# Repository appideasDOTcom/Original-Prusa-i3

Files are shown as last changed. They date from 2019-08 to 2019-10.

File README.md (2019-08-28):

# Forked from the fine folks at Prusa

Thanks to the fact that Prusa has Open Sourced their designs, I own a cheap i3 MK2 clone that has a few differences from a genuine Prusa, so their models need a few changes to work for me and others like me. My changes should stick mostly to the MK2 branch, and since Prusa doesn't appear merge that branch back to master, I won't either.

# Original Prusa i3 MK2

Original Prusa i3 MK2 is a 3D printer project maintained by PRUSA RESEARCH.
Originates in RepRap project.

This repository contains SCAD files and STLs of the printed parts.

**Links**

 * Prusa Research website : http://prusa3d.com
 * Product page : http://shop.prusa3d.com/en/3d-printers/59-original-prusa-i3-mk2-kit.html
 * Build manual : http://manual.prusa3d.com/c/Original_Prusa_i3_MK2_kit_assembly
 * Firmware : https://github.com/prusa3d/Prusa-Firmware

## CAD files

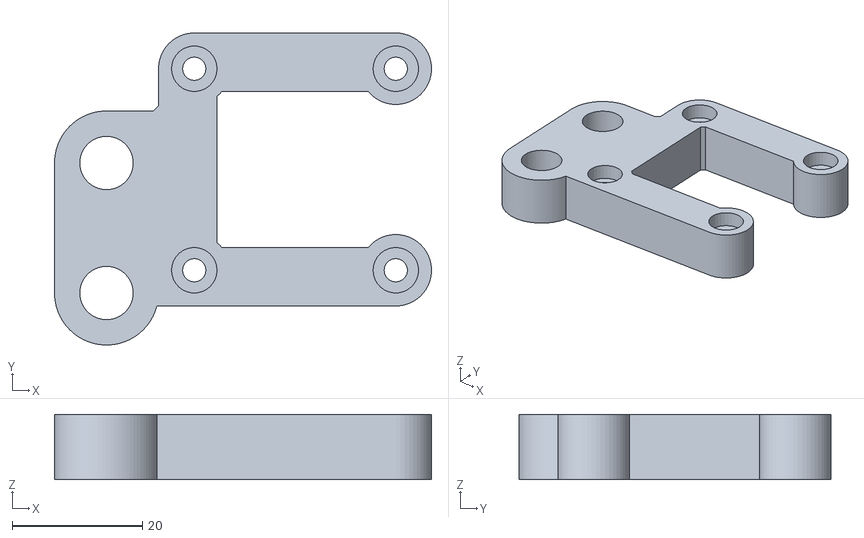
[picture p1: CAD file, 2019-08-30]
Printed-Parts/stl/y-motor.stl
58.0 x 48.0 x 10.0

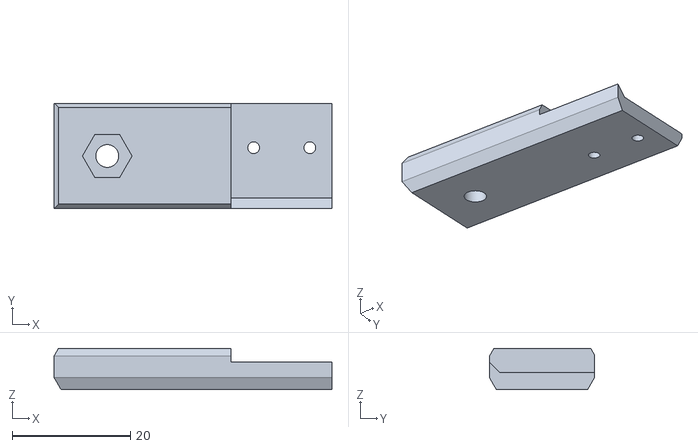
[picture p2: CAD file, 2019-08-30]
Printed-Parts/stl/x-end-adjustable-endstop-bracket.stl
47.0 x 17.8 x 7.00

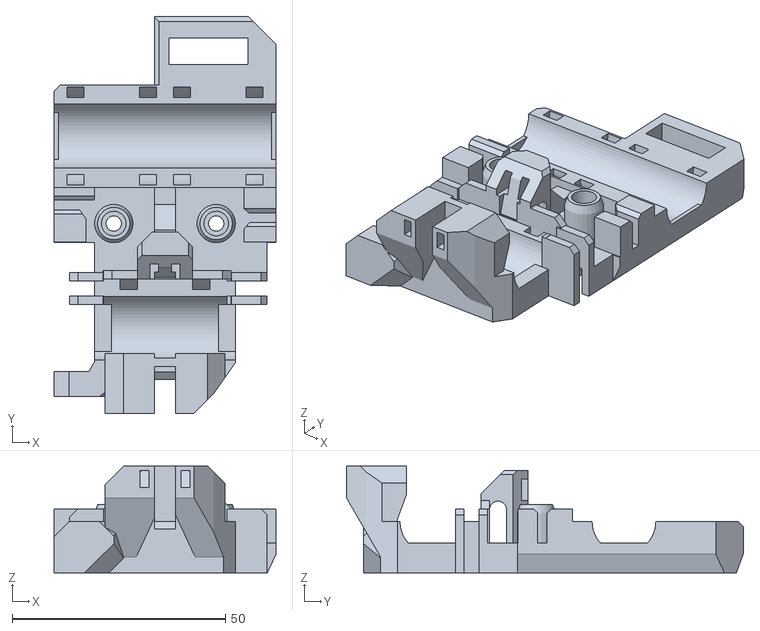
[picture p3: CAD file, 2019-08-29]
Printed-Parts/stl/x-carriage - nub right.stl
52.0 x 93.0 x 25.0

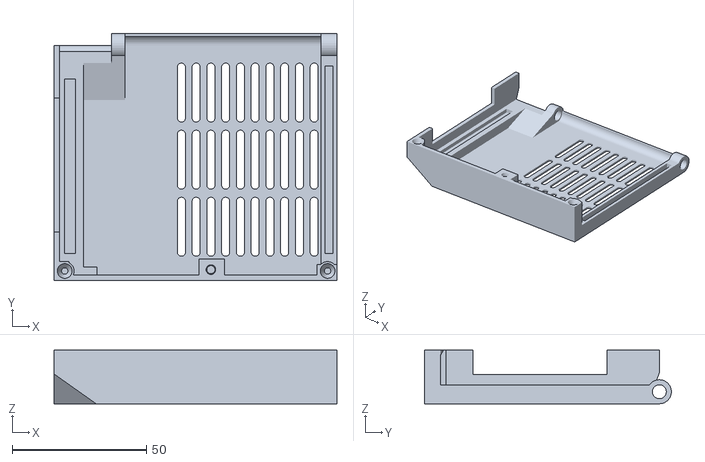
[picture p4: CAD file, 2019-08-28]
Printed-Parts/stl/RAMBo-cover-door.stl
105.5 x 92.0 x 20.0

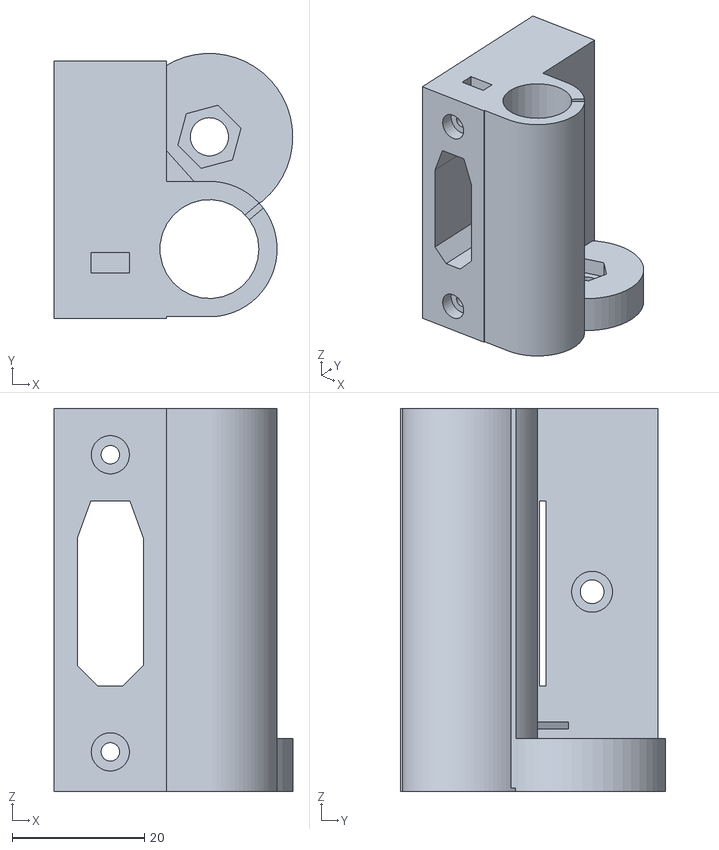
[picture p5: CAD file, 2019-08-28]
Printed-Parts/stl/x-end-idler.stl
36.1 x 40.1 x 58.0

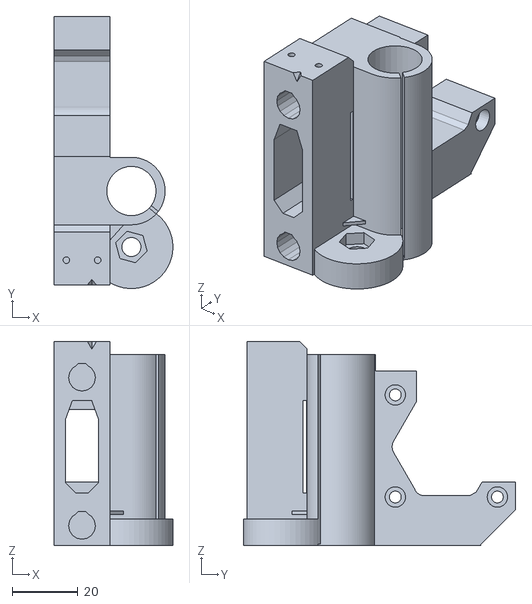
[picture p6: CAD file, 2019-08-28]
Printed-Parts/stl/x-end-motor.stl
36.1 x 82.6 x 62.0

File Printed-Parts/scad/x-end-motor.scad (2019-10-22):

// PRUSA iteration3
// X end motor
// GNU GPL v3
// Josef Průša <iam@josefprusa.cz> and contributors
// http://www.reprap.org/wiki/Prusa_Mendel
// http://prusamendel.org

use <x-end.scad>

extraBaseDepth = 8;

module x_end_motor_base(){
 x_end_base();
 translate(v=[-15,31,26.5]) cube(size = [17,44,53], center = true);
}

module x_end_motor_endstop_base(){
    translate([-23.5,-28.5,58]){
        difference(){
            // Base block
            cube([17,18.2,4]);
            // Nice edge
            translate([-1,10,10])rotate([-45,0,0])cube([20,20,20]);
            } 
        }
}

module x_end_motor_endstop_holes(){
    translate([-23.5,-28.5,58]){
        translate([17/2,7.5,-3]){
            // Back screw hole for endstop
            translate([-4.75,0,0])cylinder(r=1,h=19,$fn=20);
            // Front screw hole for endstop
            translate([4.75,0,0])cylinder(r=1,h=19,$fn=20);
            }
        }
}

module x_end_motor_holes(){
 x_end_holes();
 // Position to place
 translate(v=[-1,32,30.25]){
  // Belt hole
  translate(v=[-14,1,0]) cube(size = [10,46,22], center = true);
  // Motor mounting holes
  translate(v=[20,-15.5,-15.5]) rotate(a=[0,-90,0]) rotate(a=[0,0,90]) cylinder(h = 70, r=1.8, $fn=30);
  translate(v=[1,-15.5,-15.5]) rotate(a=[0,-90,0]) rotate(a=[0,0,90]) cylinder(h = 10 + extraBaseDepth, r=3.1, $fn=30);
  translate(v=[20,-15.5,15.5]) rotate(a=[0,-90,0]) rotate(a=[0,0,90]) cylinder(h = 70, r=1.8, $fn=30);
  translate(v=[1,-15.5,15.5]) rotate(a=[0,-90,0]) rotate(a=[0,0,90]) cylinder(h = 10 + extraBaseDepth, r=3.1, $fn=30);
   translate(v=[20,15.5,-15.5]) rotate(a=[0,-90,0]) rotate(a=[0,0,90]) cylinder(h = 70, r=1.8, $fn=30);
  translate(v=[1,15.5,-15.5]) rotate(a=[0,-90,0]) rotate(a=[0,0,90]) cylinder(h = 10 + extraBaseDepth, r=3.1, $fn=30);
  translate(v=[20,15.5,15.5]) rotate(a=[0,-90,0]) rotate(a=[0,0,90]) cylinder(h = 70, r=1.8, $fn=30);
  translate(v=[1,15.5,15.5]) rotate(a=[0,-90,0]) rotate(a=[0,0,90]) cylinder(h = 10 + extraBaseDepth, r=3.1, $fn=30); // This is the hole to nowhere

  // Material saving cutout 
  translate(v=[-10,12,10]) cube(size = [60,42,42], center = true);

  // Material saving cutout
  translate(v=[-10,40,-30]) rotate(a=[45,0,0])  cube(size = [60,42,42], center = true);
  // Motor shaft cutout
  //#translate(v=[0,0,0]) rotate(a=[0,-90,0]) rotate(a=[0,0,90]) cylinder(h = 70, r=17, $fn=6);
 }
}

// Motor shaft cutout
module x_end_motor_shaft_cutout(){
    union(){
    difference(){
        translate(v=[0,32,30]) rotate(a=[0,-90,0]) rotate(a=[0,0,90]) cylinder(h = 70, r=17, $fn=6);
       
        translate(v=[-10,-17+32,30]) cube(size = [60,2,10], center = true);
        translate(v=[-10,-8+32,-15.5+30]) rotate(a=[60,0,0]) cube(size = [60,2,10], center = true); ///
        translate(v=[-10,8+32,-15.5+30]) rotate(a=[-60,0,0]) cube(size = [60,2,10], center = true);
        
        
    }
    translate(v=[-40,25.2,-11.8 +30]) rotate(a=[0,90,0]) cylinder(h = 40, r=3, $fn=30);
    translate(v=[-40,19.05,30]) rotate(a=[0,90,0]) cylinder(h = 40, r=3.5, $fn=100);
}
}




// Final part
module x_end_motor(){
 difference(){
     union(){
            x_end_motor_base();
            x_end_motor_endstop_base();
            extraBase();
         }
  x_end_motor_shaft_cutout();
  x_end_motor_holes();
  x_end_motor_endstop_holes();    
      
      translate([-12,-42,65]) rotate([-35,0,0])  rotate([0,0,45]) cube([10,10,10]);
      translate([-15,8.5,6]) rotate([90,0,0]) cylinder(h=5, r=5, $fn=30);   
      translate([-15,8.5,51]) rotate([90,0,0]) cylinder(h=5, r=5, $fn=30);   
      translate([-15,3.5,6]) rotate([90,0,0]) cylinder(h=3, r1=5, r2=4, $fn=30);   
      translate([-15,3.5,51]) rotate([90,0,0]) cylinder(h=3, r1=5, r2=4, $fn=30); 
      //#translate([-16,-40,0])cube([50,100,100]);   
 }
 
}

module extraBase()
{
    translate( [-31.5, 10.5, 0] )
    {
        cube( [extraBaseDepth, 42.5, 53] );
    }

}

// x_end_motor();

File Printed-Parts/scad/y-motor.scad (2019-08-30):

// PRUSA iteration3
// Y motor mount
// GNU GPL v3
// Josef Průša <iam@josefprusa.cz> and contributors
// http://www.reprap.org/wiki/Prusa_Mendel
// http://prusamendel.org

//include <configuration.scad>

renderEndstopMount = false;

module motorMountArm()
{
   translate(v = [-21+4.5,0,5]) cube(size = [9,31,10], center=true);
   translate(v = [-15.5,-15.5,0]) cylinder(h = 10, r=5.5, $fn=50);
   translate(v = [-15.5,+15.5,0]) cylinder(h = 10, r=5.5, $fn=50);
}

// Pull Prusa's motor mount into a module so it's easier to work with in isolation
module motorMount()
{
// Motor holding part
   translate(v = [29,-21+50,0])
   {
      translate(v = [-21+4.5,0,5]) cube(size = [9,31,10], center=true);
      translate(v = [-15.5,-15.5,0]) cylinder(h = 10, r=5.5, $fn=50);
      translate(v = [-15.5,+15.5,0]) cylinder(h = 10, r=5.5, $fn=50);
      translate([-21,7,0]) rotate([0,0,45]) cube([2, 2, 10]);

      difference()
      {
         {
            union()
            {
               rotate( [0, 0, 90] ) 
               {
                  motorMountArm();
               }
               rotate( [0, 0, -90] ) 
               {
                  motorMountArm();
               }
            }
         }
         {
            translate( [31, 0, 0] )
            {
               boltHoles();
            }
         }
      }

      //end stop
      // My printer's end-stop is on the opposite end of the motor mount
      if( renderEndstopMount )
      {
         translate(v = [-10.5,+15.5,0]) cylinder(h = 10, r=5.5, $fn=50);
         translate([-12,0,0]) cube([7, 15, 10]);
         translate([-16,16,0]) cube([6, 5, 10]);
         translate([-21+6,8,0]) cube([12-2, 5, 28]);
         translate([-21+6-2,8-5,0]) cube([4, 10, 28]);
         translate([-21+9.5-2,7,0]) rotate([0,0,45]) cube([2, 2, 28]);    
      }

   // Joins motor holder and rod plate
   translate(v = [-29,-21,0]) cube(size = [14,30,10]);
 }
}

module y_motor_base(){
 
motorMount();

 // Front holding part
 translate(v = [0,10,0]) cylinder(h = 10, r=8, $fn=80);
 translate(v = [0,20,5])cube(size = [16,20,10], center=true);	
 translate(v = [0,30,0])cylinder(h = 10, r=8, $fn=80);
}

module boltHoles()
{
   // Screw head holes
  translate(v = [-15.5,-15.5,-1]) cylinder(h = 10, r=1.8, $fn=20);
  translate(v = [-15.5,+15.5,-1]) cylinder(h = 10, r=1.8, $fn=20);
  // Screw holes
  translate(v = [-15.5,-15.5,7]) cylinder(h = 7, r=3.5, $fn=30);
  translate(v = [-15.5,+15.5,7]) cylinder(h = 25, r=3.5, $fn=30);
}

module y_motor_holes(){
 translate(v = [29,-21+50,0]){
  boltHoles();
 }
 translate(v = [0,10,-1]) cylinder(h = 12, r=4.1, $fn=50);	
 translate(v = [0,30,-1]) cylinder(h = 12, r=4.1, $fn=50);
 
 //endstop
    translate([25,29,0])  cylinder(h = 29, r=8, $fn=20); 
   
    translate([18,45,15]) rotate([90,0,0]) cylinder(h = 10, r=0.8, $fn=20);
    translate([18,42.2,15]) rotate([90,0,0]) cylinder(h = 2, r1=1.2, r2=0.8, $fn=20);
 
    translate([18,45,24.5]) rotate([90,0,0]) cylinder(h = 10, r=0.8, $fn=20);
    translate([18,42.2,24.5]) rotate([90,0,0]) cylinder(h = 2, r1=1.2, r2=0.8, $fn=20);
   
    // endstop corner cutout
    translate([-5-2,30,28]) rotate([0,45,0]) cube([15, 19, 15]);	
    translate([-1,41,10])  cube([15, 5, 19]);	
    translate([27,33,0]) rotate([0,0,45]) cube([5, 5, 28]);	
    translate([12-2,28,10.01]) rotate([0,0,45]) cube([5, 5, 28]);
    
    // This cuts through the extended Y motor mount arm
    //translate([19,32,0]) rotate([0,30,0]) cube([8, 20, 18]);	
    translate([24.5-2,32,17]) rotate([0,45,0]) cube([2, 20, 2]);	
    
    translate([23-2,32,29]) rotate([0,45,0]) cube([5, 20, 5]);	
}




//#translate([18,40,10]) cube([8, 5, 5]);	

// Final part
module y_motor(){
 difference(){
  y_motor_base();
  y_motor_holes();
 }
}

y_motor();

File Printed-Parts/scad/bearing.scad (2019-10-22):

// PRUSA iteration3
// Bearing holders
// GNU GPL v3
// Josef Průša <iam@josefprusa.cz> and contributors
// http://www.reprap.org/wiki/Prusa_Mendel
// http://prusamendel.org

use <polyholes.scad>

bearing_diameter = 14.8; // The actual cutout below adds 0.1 to this number. Why set it here?!

module horizontal_bearing_base(bearings=1){
 translate(v=[0,0,6]) cube(size = [24,8+bearings*25,12], center = true);	
}
module horizontal_bearing_holes(bearings=1){
 cutter_lenght = 10+bearings*25;
 one_holder_lenght = 8+25;
 holder_lenght = 8+bearings*25;
 
 // Main bearing cut
 difference(){
  translate(v=[0,0,12]) rotate(a=[90,0,0]) translate(v=[0,0,-cutter_lenght/2]) cylinder(h = cutter_lenght, r=(bearing_diameter/2)+0.2, $fn=50);
  // Bearing retainers
  translate(v=[0,1-holder_lenght/2,3]) cube(size = [24,6,8], center = true);
  translate(v=[0,-1+holder_lenght/2,3]) cube(size = [24,6,8], center = true);
 }
 
 // Ziptie cutouts
 ziptie_cut_ofset = 0;
 for ( i = [0 : bearings-1] ){
  // For easier positioning I move them by half of one 
  // bearing holder then add each bearign lenght and then center again
  translate(v=[0,-holder_lenght/2,0]) translate(v=[0,one_holder_lenght/2+i*25,0]) difference(){
   union(){
    translate(v=[0,2-8.5,12]) rotate(a=[90,0,0]) translate(v=[0,0,0]) cylinder(h = 4, r=11.5, $fn=50);
    translate(v=[0,2+8.5,12]) rotate(a=[90,0,0]) translate(v=[0,0,0]) cylinder(h = 4, r=11.5, $fn=50);
   }
   translate(v=[0,12,12]) rotate(a=[90,0,0]) translate(v=[0,0,0]) cylinder(h = 24, r=9, $fn=50);
  }
 }
 
}

module horizontal_bearing_test(){
 difference(){
  horizontal_bearing_base(1);
  horizontal_bearing_holes(1);
 }
 translate(v=[30,0,0]) difference(){
  horizontal_bearing_base(2);
  #horizontal_bearing_holes(2);
 }
 translate(v=[60,0,0]) difference(){
  horizontal_bearing_base(3);
  horizontal_bearing_holes(3);
 }
}



thinwall = 3;
bearing_size = bearing_diameter + 2 * thinwall;

module vertical_bearing_base(){
 translate(v=[-2-bearing_size/4,0,29]) cube(size = [4+bearing_size/2,bearing_size,58], center = true);
 cylinder(h = 58, r=bearing_size/2, $fn = 90);
}

module vertical_bearing_holes(){
  translate(v=[0,0,-1]) poly_cylinder(h = 62, r=(bearing_diameter/2)+0.1);
  rotate(a=[0,0,-40]) translate(v=[bearing_diameter/2-2.9,-0.5,0.5]) cube(size = [thinwall*2,1,62]);

}

//difference(){
vertical_bearing_base();
vertical_bearing_holes();
//}
//horizontal_bearing_test();
//horizontal_bearing_base(1);
//horizontal_bearing_holes(1);

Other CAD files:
Printed-Parts/stl/x-carriage - nub left.stl
Printed-Parts/stl/x-carriage.stl
Printed-Parts/scad/RAMBo-cover-door.scad
Printed-Parts/scad/x-carriage.scad
Printed-Parts/scad/x-end-adjustable-endstop-bracket.scad
Printed-Parts/scad/x-end-idler.scad
Printed-Parts/scad/x-end.scad

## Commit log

2019-08-28 X carriage motor mount: - Replace lead screw mechanism with one for a threaded rod and captured M5 nut - Fixed a couple of console errors in the original code
    [x-end-motor.scad, x-end.scad]
2019-08-28 Rendered X carriage ends (motor and idler mounts) for M5 threaded rod and captured nut to replace Prusa's proper lead screw and trapezoidal nut
    [x-end-idler.stl, x-end-motor.stl]
2019-08-28 X carriage that's slightly less Prusa-specific: - Remove rear filament feed hole - Replace elements of "carriage fancy" with a hole that can be used for securing wires - Remove visibility of highligh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
    [x-carriage.scad]
2019-08-28 Rendered X carriage for other-than-Prusa printers
    [x-carriage.stl]
2019-08-28 Added top cutout to electronics enclosure (RAMBo) door for those of us whose wires are the wrong size, shape or length to exit out the side
    [RAMBo-cover-door.scad, RAMBo-cover-door.stl]
2019-08-28 Move the endstop trigger nub to the other side of the carriage. It can be moved back by changing a variable.
    [x-carriage.scad]
2019-08-28 Rendered models with the X axis endstop trigger nub on either side
    [x-carriage - nub left.stl, x-carriage - nub right.stl]
2019-08-28 Moved STL files to the correct folder
    [x-carriage - nub left.stl, x-carriage - nub right.stl]
2019-08-29 Files named properly according to the nub side
    [x-carriage - nub left.stl, x-carriage - nub right.stl]
2019-08-29 Add bezel to X carriage piece for aesthetics
    [x-carriage - nub left.stl, x-carriage - nub right.stl, x-carriage.scad]
2019-08-30 Mountable arm for the motor mount that allows the addition of a Z axis adjustment bolt
    [x-end-adjustable-endstop-bracket.scad, x-end-adjustable-endstop-bracket.stl]
2019-08-30 Modified Y motor mount: - Add bolt holes for applications where are four bolts are needed (e.g. adding a vibration damper) - Remove endstop mount (by default) for printers with the endstop on the oth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
    [y-motor.scad, y-motor.stl]
2019-09-03 Added TODO comments
    [x-end-idler.scad]
2019-09-29 Revert back to original T8 lead screw mechanism to be modified to use an 8mm copper nut and more standard pulley
    [x-end.scad]
2019-09-29 Make room for a 6mm pulley
    [x-end.scad]
2019-09-29 Modify lead screw nut for the more rectangular style
    [x-end.scad]
2019-10-22 - Correct diameter for using RJ4JP bearings in X end pieces - Added depth to the X end motor mount so that a pulley can be properly installed instead of backwards and with barely any grip area
    [bearing.scad, x-end-motor.scad]
2019-10-22 Don't automatically render the piece
    [x-end-idler.scad]
